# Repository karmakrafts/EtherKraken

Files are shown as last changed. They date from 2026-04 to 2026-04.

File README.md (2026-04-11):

# EtherKraken

An RP3A0 SiP based controller board with 38 programmable IOs, 2MB of flash, SPI, I²C, UART and 100Base-T connectivity
for embedded- and automation-applications.

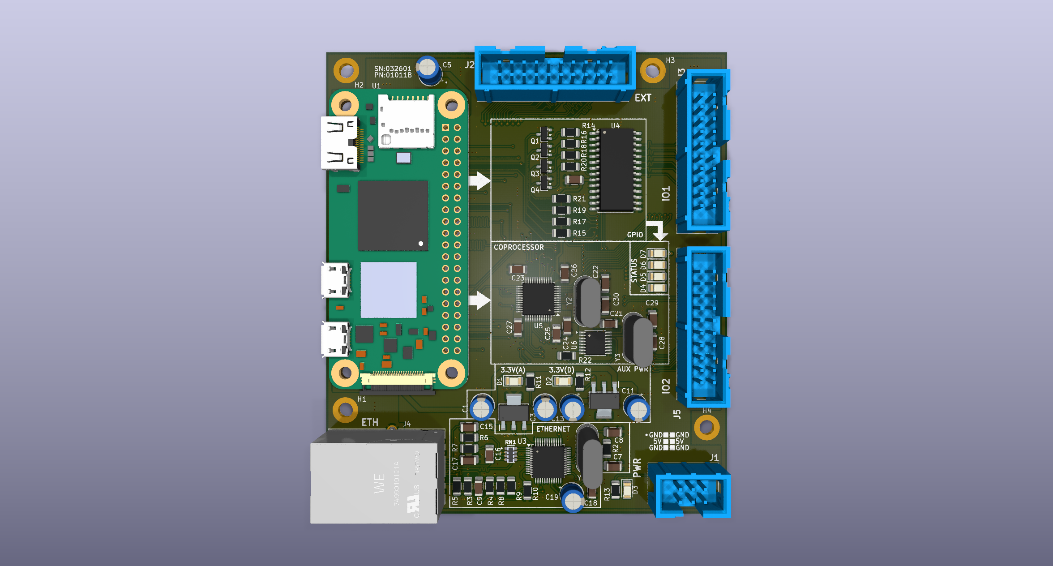
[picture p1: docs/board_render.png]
3D render of the circuit board


### Building libkraken

In order to build the `libkraken` hardware abstraction layer library,  
a computer or VM with a Debian/Ubuntu based Linux distribution is recommended.

The following dependencies are required:

```
build-essential clang-20 llvm-20 make cmake
```

You will also need the Clang RT libraries from an LLVM aarch64 sysroot,  
which you can obtain by downloading a prebuilt LLVM package [from here](https://github.com/llvm/llvm-project/releases)
and  
copying the `aarch-64-unknown-linux-gnu` directory in `LLVM-XX.X.X-Linux-ARM64/lib/clang/XX/lib`  
to `/usr/lib/llvm-XX/lib/clang/XX/lib`.

When you have all dependencies installed, simply invoke `build.sh` in the `libkraken` directory.

The toolchain configuration can be found in `libkraken/cmake/toolchain.cmake` and may be customized as desired.

### Building etherkraken-core

`etherkraken-core` is the high level Kotlin/Native wrapper around the `libkraken` HAL.  
In order to build it, you only need [a JDK](https://www.azul.com/downloads/?package=jdk#zulu) on an Ubuntu/Debian based
Linux distribution.

Simply run the following command in the root of the repository:

```shell
./gradlew build
```

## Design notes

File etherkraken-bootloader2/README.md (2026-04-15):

# EtherKraken bootloader2

bootloader2 (or BL2) is a second stage bootloader for the co-processor  
on the EtherKraken controller board,  
which allows sideloading and flashing firmware via UART to facilitate debugging  
and updates coordinated by the main processor.

### Building

For building EtherKraken bootloader2, a machine or VM with an Ubuntu based distribution  
is recommended. Ensure you have all dependencies installed before proceeding by
running the following command:

```shell
sudo apt install -y build-essential curl wget unzip xz-utils \
	git cmake python3 clang-20 llvm-20 gcc-arm-none-eabi
```

When you have all dependencies installed, simply invoke the image buildscript:

```shell
./build.sh
```

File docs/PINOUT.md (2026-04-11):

# EtherKraken Pinout

The following tables denote the pinouts of all ports and peripherals on
the EtherKraken v1 Rev. B board.  
The Raspberry Pi Zero 2W daughterboard uses the regular BCM2835 GPIO pinout.

### Status LEDs

| Name | Description  | Connects to |
|---|---|---|
| `ST_LED0` | Status LED 0 | MCP23017 GPB4/Pin 5 |
| `ST_LED1` | Status LED 1 | MCP23017 GPB5/Pin 6 |
| `ST_LED2` | Status LED 2 | MCP23017 GPB6/Pin 7 |
| `ST_LED3` | Status LED 3 | MCP23017 GPB7/Pin 8 |

### PWR Port

| Pin | Name | Description | Connects to |
|-----|---|---|---|
| 1 | `GND`  | | GND |
| 3 | `VCC5` | 5V main supply | VCC5 |
| 5 | `GND`  | | GND |
| 2 | `GND`  | | GND |
| 4 | `VCC5` | 5V main supply | VCC5 |
| 6 | `GND`  | | GND |

### EXT Port

| Pin | Name | Description | Connects to |
|-----|---|---|---|
| 1 | `I2C_SCL` | I²C clock | RP3A0 GPIO 3/Pin 5 |
| 3 | `I2C_SDA` | I²C data | RP3A0 GPIO 2/Pin 3 |
| 5 | `GND` | | GND |
| 7 | `GND` | | GND |
| 9 | `SPI1_CE1` | SPI1 chip enable 1 | RP3A0 GPIO 17/Pin 11 |
| 11  | `SPI1_CE2` | SPI1 chip enable 2 | RP3A0 GPIO 16/Pin 36 |
| 13  | `SPI1_MISO`  | SPI1 data from slave | RP3A0 GPIO 19/Pin 35 |
| 15  | `SPI1_MOSI`  | SPI1 data to slave | RP3A0 GPIO 20/Pin 38 |
| 17  | `SPI1_SCLK`  | SPI1 clock | RP3A0 GPIO 21/Pin 40 |
| 19  | `GND` | | GND |
| 2 | `UART_TX` | UART transmit | RP3A0 GPIO 14/Pin 8  |
| 4 | `UART_RX` | UART receive | RP3A0 GPIO 15/Pin 10 |
| 6 | `GND` | | GND |
| 8 | `CO_RST` | Co-processor reset | RP3A0 GPIO 22/Pin 15 |
| 10  | `CO_BOOT` | Co-processor boot mode | RP3A0 GPIO 23/Pin 16 |
| 12  | `CO_SINT` | Co-processor serial interrupt | RP3A0 GPIO 24/Pin 18 |
| 14  | `AUX0` | Auxillary GPIO 0 | RP3A0 GPIO 25/Pin 22 |
| 16  | `AUX1` | Auxillary GPIO 1 | RP3A0 GPIO 26/Pin 37 |
| 18  | `AUX_PWR_EN` | Auxillary power enable (3.3V) | RP3A0 GPIO 27/Pin 13 |
| 20  | `GND` | | GND |

### IO0 Port

| Pin | Name | Description | Connects to |
|-----|---|---|---|
| 1 | `GND` | | GND |
| 3 | `IO_A0` | Primary GPIO 0 | STM32 PA0/Pin 10 |
| 5 | `IO_A1` | Primary GPIO 1 | STM32 PA1/Pin 11 |
| 7 | `IO_A2` | Primary GPIO 2 | STM32 PA2/Pin 12 |
| 9 | `IO_A3` | Primary GPIO 3 | STM32 PA3/Pin 13 |
| 11  | `IO_A4` | Primary GPIO 4 | STM32 PA4/Pin 14 |
| 13  | `IO_A5` | Primary GPIO 5 | STM32 PA5/Pin 15 |
| 15  | `IO_A6` | Primary GPIO 6 | STM32 PA6/Pin 16 |
| 17  | `IO_A7` | Primary GPIO 7 | STM32 PA7/Pin 17 |
| 19  | `GND` | | GND |
| 2 | `GND` | | GND |
| 4 | `IO_B0` | Secondary GPIO 0 | MCP23017 GPA0/Pin 21 |
| 6 | `IO_B1` | Secondary GPIO 1 | MCP23017 GPA0/Pin 22 |
| 8 | `IO_B2` | Secondary GPIO 2 | MCP23017 GPA0/Pin 23 |
| 10  | `IO_B3` | Secondary GPIO 3 | MCP23017 GPA0/Pin 24 |
| 12  | `IO_B4` | Secondary GPIO 4 | MCP23017 GPA0/Pin 25 |
| 14  | `IO_B5` | Secondary GPIO 5 | MCP23017 GPA0/Pin 26 |
| 16  | `IO_A8` | Primary GPIO 8 | STM32 PA8/Pin 29 |
| 18  | `IO_A9` | Primary GPIO 9 | STM32 PB0/Pin 18 |
| 20  | `GND` | | GND |

### IO1 Port

| Pin | Name | Description | Connects to |
|-----|---|---|---|
| 1 | `GND` | | GND |
| 3 | `IO_A10` | Primary GPIO 10 | STM32 PB1/Pin 19 |
| 5 | `IO_A11` | Primary GPIO 11 | STM32 PB2/Pin 20 |
| 7 | `IO_A12` | Primary GPIO 12 | STM32 PB3/Pin 39 |
| 9 | `IO_A13` | Primary GPIO 13 | STM32 PA13/Pin 34 |
| 11  | `IO_A14` | Primary GPIO 14 | STM32 PA14/Pin 37 |
| 13  | `IO_A15` | Primary GPIO 15 | STM32 PA15/Pin 38 |
| 15  | `IO_A16` | Primary GPIO 16 | STM32 PB4/Pin 40 |
| 17  | `IO_A17` | Primary GPIO 17 | STM32 PB5/Pin 41 |
| 19  | `GND` | | GND |
| 2 | `GND` | | GND |
| 4 | `IO_B6`  | Secondary GPIO 6  | MCP23017 GPA6/Pin 27 |
| 6 | `IO_B7`  | Secondary GPIO 7  | MCP23017 GPA7/Pin 28 |
| 8 | `IO_B8`  | Secondary GPIO 8  | MCP23017 GPB0/Pin 1  |
| 10  | `IO_B9`  | Secondary GPIO 9  | MCP23017 GPB1/Pin 2  |
| 12  | `IO_B10` | Secondary GPIO 10 | MCP23017 GPB2/Pin 3  |
| 14  | `IO_B11` | Secondary GPIO 11 | MCP23017 GPB3/Pin 4  |
| 16  | `IO_A18` | Primary GPIO 18 | STM32 PB6/Pin 42 |
| 18  | `IO_A19` | Primary GPIO 19 | STM32 PB7/Pin 43 |
| 20  | `GND` | | GND |

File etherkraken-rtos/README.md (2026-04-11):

# EtherKraken RTOS

EtherKraken RTOS is a modified version of Raspberry Pi OS Lite, incorporating  
PREEMPT_RT kernel patches, default configurations and custom software.

### Building

For building EtherKraken RTOS, a machine or VM with an Ubuntu based distribution  
is recommended. Ensure you have all dependencies installed before proceeding by
running the following command:

```shell
sudo apt install -y build-essential curl wget unzip xz-utils \
    git bc bison flex libncurses5-dev libssl-dev \
    crossbuild-essential-arm64 kmod rsync \
    device-tree-compiler parted
```

When you have all dependencies installed, simply invoke the image buildscript:

```shell
sudo ./build.sh
```

> **Note:** root permission is required to run the buildscript, since it 
> interacts with loopback devices on the build host.

The build was last successfully tested on **PopOS 24.04**.

### Configuration

The default build configuration is specified in `build.sh` directly and may  
be changed as required.  
The default user is `etherkraken` with the default password of `etherkraken`.

#### Boot

The boot configuration may be changed by adjusting `boot/config.txt` and  
`boot/cmdline.txt` accordingly.  
The latter will be appended to the default `cmdline.txt` already included  
in the base image.

#### Network

If a default network configuration should be baked into the built image,  
a `network-config` file needs to be placed in `etherkraken-rtos` root directory  
before invoking `build.sh`.

An example of this can be found in `example/network-config`.

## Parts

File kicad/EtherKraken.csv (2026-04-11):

Reference | Qty | Value | DNP | Exclude from BOM | Exclude from Board | Footprint | Datasheet
C1 | 1 | 2,2µF |  |  |  | Capacitor_THT:CP_Radial_D5.0mm_P2.00mm
C2,C4,C6,C10,C12,C14,C20,C23,C24,C25,C26,C27,C30 | 13 | 100nF |  |  |  | Capacitor_SMD:C_1206_3216Metric
C3,C11 | 2 | 4,7µF |  |  |  | Capacitor_THT:CP_Radial_D5.0mm_P2.00mm
C5,C13 | 2 | 10µF |  |  |  | Capacitor_THT:CP_Radial_D5.0mm_P2.00mm
C7,C8,C21,C22 | 4 | 18pF |  |  |  | Capacitor_SMD:C_1206_3216Metric
C9 | 1 | 22nF |  |  |  | Capacitor_SMD:C_1206_3216Metric
C15,C16 | 2 | 6.8nF |  |  |  | Capacitor_SMD:C_1206_3216Metric
C17,C18 | 2 | 10nF |  |  |  | Capacitor_SMD:C_1206_3216Metric
C19 | 1 | 4.7µF |  |  |  | Capacitor_THT:CP_Radial_D5.0mm_P2.00mm
C28 | 1 | 22pF |  |  |  | Capacitor_SMD:C_1206_3216Metric
C29 | 1 | 33pF |  |  |  | Capacitor_SMD:C_1206_3216Metric
D1,D2,D3,D4,D5,D6,D7 | 7 | LED |  |  |  | LED_SMD:LED_1206_3216Metric
IC1,IC2 | 2 | NCV33375ST3.3T3G |  |  |  | parts:SOT230P700X175-4N | https://www.onsemi.com/pub/Collateral/MC33375-D.PDF
J1 | 1 | Conn_02x03_Odd_Even |  |  |  | parts:09185066324_02x03_P2.54
J2,J3,J5 | 3 | Conn_02x10_Odd_Even |  |  |  | parts:09185206324_02x10_P2.54
J4 | 1 | RJ45_Wuerth_7499010121A |  |  |  | Connector_RJ:RJ45_Wuerth_7499010121A_Horizontal | http://katalog.we-online.de/pbs/datasheet/7499010121A.pdf
Q1,Q2,Q3,Q4 | 4 | MMBT3904 |  |  |  | Package_TO_SOT_SMD:SOT-23 | https://www.onsemi.com/pdf/datasheet/pzt3904-d.pdf
R1,R22 | 2 | 10k |  |  |  | Resistor_SMD:R_1206_3216Metric
R2 | 1 | 1M |  |  |  | Resistor_SMD:R_1206_3216Metric
R3,R4,R6,R7 | 4 | 49,9R |  |  |  | Resistor_SMD:R_1206_3216Metric
R5 | 1 | 10R |  |  |  | Resistor_SMD:R_1206_3216Metric
R8,R9 | 2 | 330R |  |  |  | Resistor_SMD:R_1206_3216Metric
R10 | 1 | 12.4k |  |  |  | Resistor_SMD:R_1206_3216Metric
R11,R12 | 2 | 51R |  |  |  | Resistor_SMD:R_1206_3216Metric
R13 | 1 | 150R |  |  |  | Resistor_SMD:R_1206_3216Metric
R14,R16,R18,R20 | 4 | 1,2k |  |  |  | Resistor_SMD:R_1206_3216Metric
R15,R17,R19,R21 | 4 | 62R |  |  |  | Resistor_SMD:R_1206_3216Metric
RN1 | 1 | 33R |  |  |  | parts:R_Array_Convex_8N_1206
U1 | 1 | RASPBERRY_PI_ZERO_2_W |  |  |  | parts:MODULE_RASPBERRY_PI_ZERO_2_W
U2 | 1 | AT45DB641E-SHN-T |  |  |  | Package_SO:SOIC-8_5.3x5.3mm_P1.27mm
U3 | 1 | W5500 |  |  |  | Package_QFP:LQFP-48_7x7mm_P0.5mm | http://wizwiki.net/wiki/lib/exe/fetch.php/products:w5500:w5500_ds_v109e.pdf
U4 | 1 | MCP23017x-x-SO |  |  |  | Package_SO:SOIC-28W_7.5x17.9mm_P1.27mm | https://ww1.microchip.com/downloads/aemDocuments/documents/APID/ProductDocuments/DataSheets/MCP23017-Data-Sheet-DS20001952.pdf
U5 | 1 | STM32F071CBTx |  |  |  | Package_QFP:LQFP-48_7x7mm_P0.5mm | https://www.st.com/resource/en/datasheet/stm32f071cb.pdf
U6 | 1 | SC16IS740 |  |  |  | Package_SO:TSSOP-16_4.4x5mm_P0.65mm | https://www.nxp.com/docs/en/data-sheet/SC16IS740_750_760.pdf
Y1 | 1 | 25MHz |  |  |  | Crystal:Crystal_HC49-U_Vertical
Y2 | 1 | 8MHz |  |  |  | Crystal:Crystal_HC49-U_Vertical
Y3 | 1 | 1,8432MHz |  |  |  | Crystal:Crystal_HC49-U_Vertical

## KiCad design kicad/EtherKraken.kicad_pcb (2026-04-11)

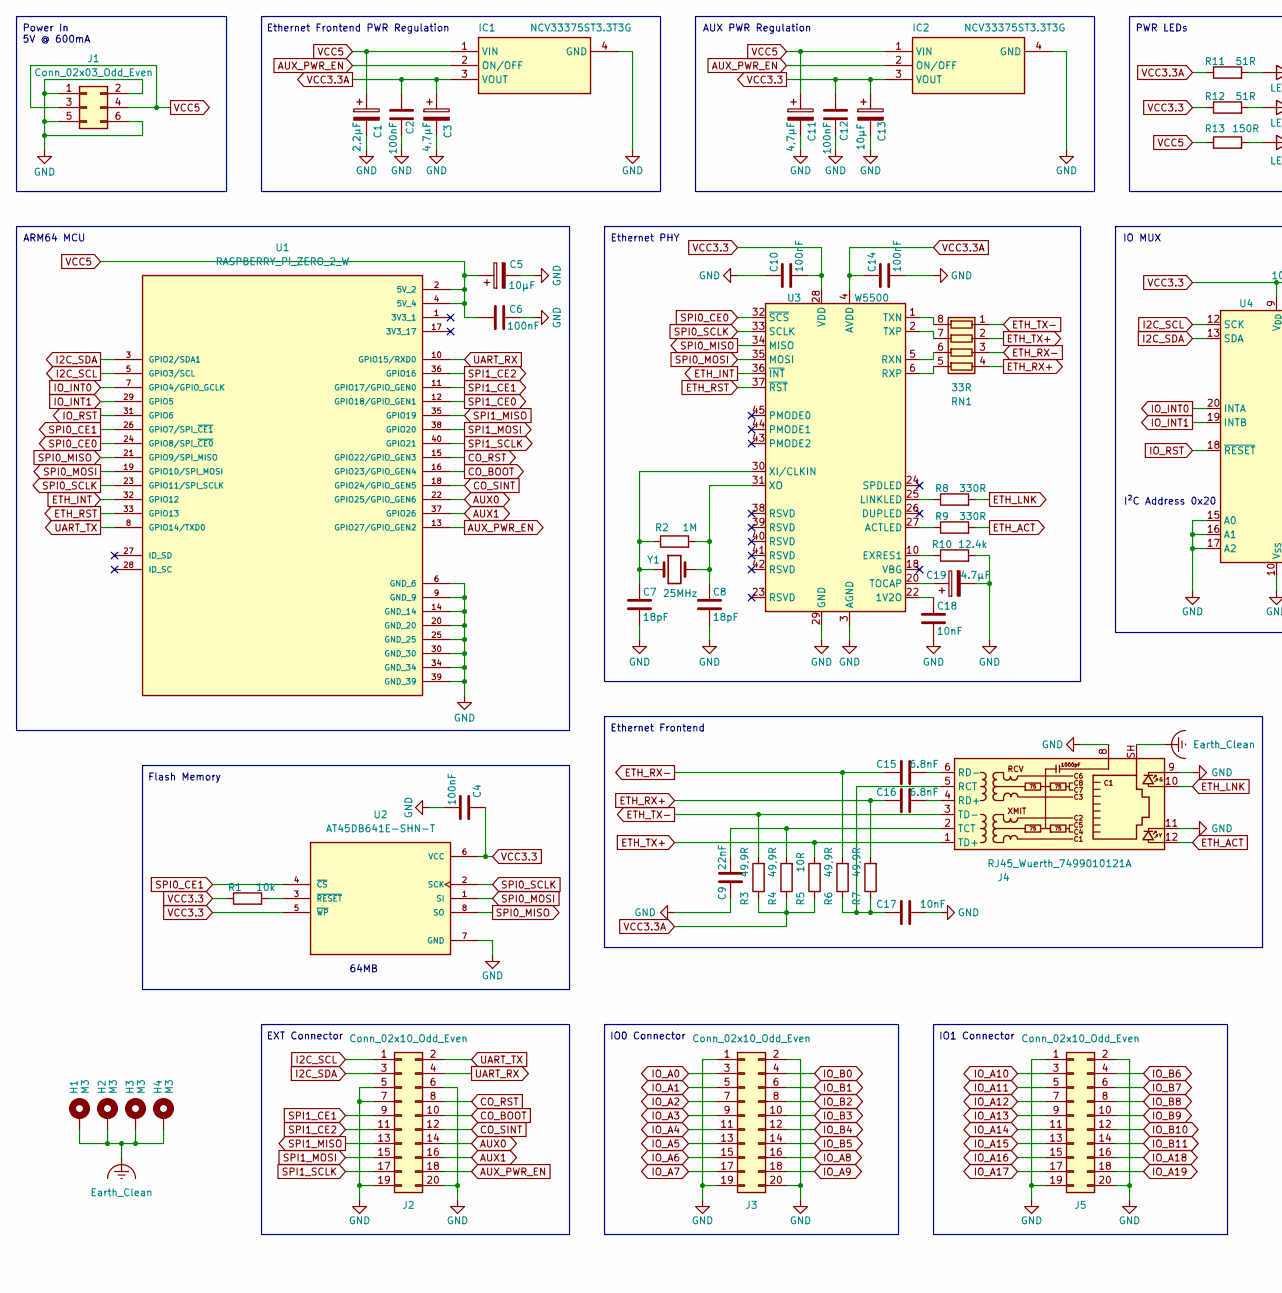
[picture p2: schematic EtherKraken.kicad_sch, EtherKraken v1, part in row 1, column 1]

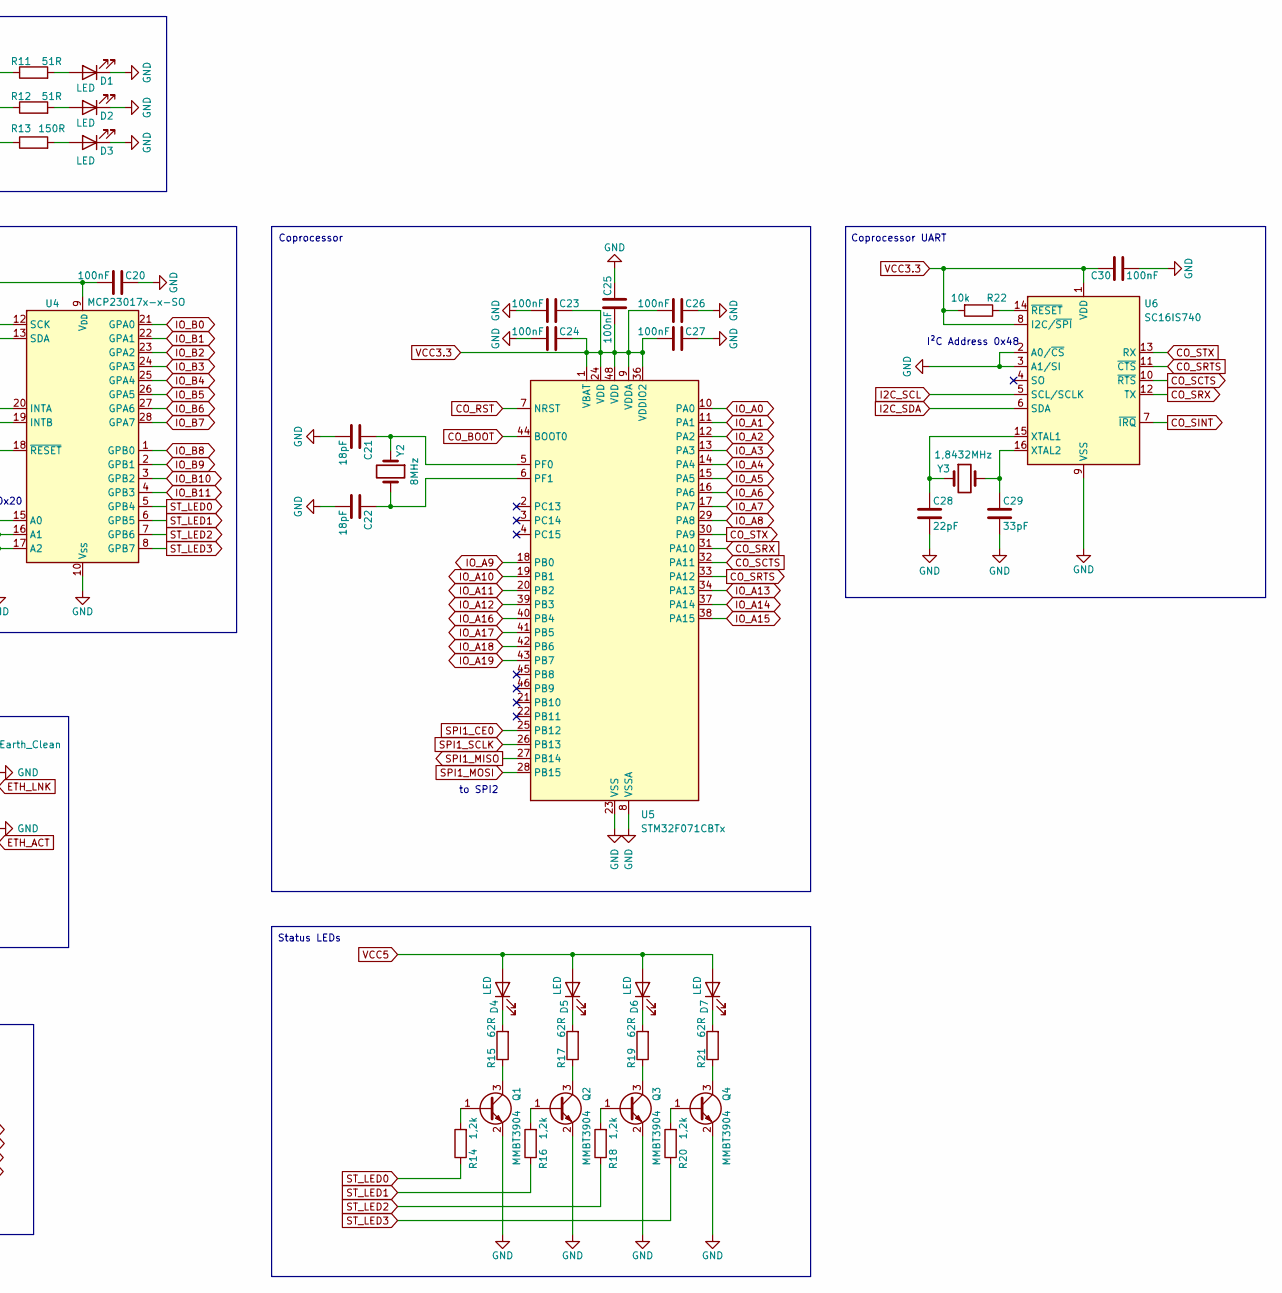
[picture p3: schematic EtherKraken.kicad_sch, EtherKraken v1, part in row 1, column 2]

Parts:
C1: 2,2µF; CP_Radial_D5.0mm_P2.00mm
C2, C4, C6, C10, C12, C14, C20, C23, C24, C25, C26, C27, C30: 100nF; C_1206_3216Metric
C3, C11: 4,7µF; CP_Radial_D5.0mm_P2.00mm
C5, C13: 10µF; CP_Radial_D5.0mm_P2.00mm
C7, C8, C21, C22: 18pF; C_1206_3216Metric
C9: 22nF; C_1206_3216Metric
C15, C16: 6.8nF; C_1206_3216Metric
C17, C18: 10nF; C_1206_3216Metric
C19: 4.7µF; CP_Radial_D5.0mm_P2.00mm
C28: 22pF; C_1206_3216Metric
C29: 33pF; C_1206_3216Metric
D1, D2, D3, D4, D5, D6, D7: LED; LED_1206_3216Metric
H1, H2, H3, H4: M3; MountingHole_3.2mm_M3_DIN965_Pad
IC1, IC2: NCV33375ST3.3T3G; SOT230P700X175-4N; Mouser Part Number 863-NCV33375ST3.3T3G
J1: Conn_02x03_Odd_Even; 09185066324_02x03_P2.54
J2, J3, J5: Conn_02x10_Odd_Even; 09185206324_02x10_P2.54
J4: RJ45_Wuerth_7499010121A; RJ45_Wuerth_7499010121A_Horizontal
Q1, Q2, Q3, Q4: MMBT3904; SOT-23
R1, R22: 10k; R_1206_3216Metric
R2: 1M; R_1206_3216Metric
R3, R4, R6, R7: 49,9R; R_1206_3216Metric
R5: 10R; R_1206_3216Metric
R8, R9: 330R; R_1206_3216Metric
R10: 12.4k; R_1206_3216Metric
R11, R12: 51R; R_1206_3216Metric
R13: 150R; R_1206_3216Metric
R14, R16, R18, R20: 1,2k; R_1206_3216Metric
R15, R17, R19, R21: 62R; R_1206_3216Metric
RN1: 33R; R_Array_Convex_8N_1206
U1: RASPBERRY_PI_ZERO_2_W; MODULE_RASPBERRY_PI_ZERO_2_W; PARTREV April 2024
U2: AT45DB641E-SHN-T; SOIC-8_5.3x5.3mm_P1.27mm
U3: W5500; LQFP-48_7x7mm_P0.5mm
U4: MCP23017x-x-SO; SOIC-28W_7.5x17.9mm_P1.27mm
U5: STM32F071CBTx; LQFP-48_7x7mm_P0.5mm
U6: SC16IS740; TSSOP-16_4.4x5mm_P0.65mm
Y1: 25MHz; Crystal_HC49-U_Vertical
Y2: 8MHz; Crystal_HC49-U_Vertical
Y3: 1,8432MHz; Crystal_HC49-U_Vertical

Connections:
AUX0: J2.14, U1.22 (GPIO25/GPIO_GEN6)
AUX1: J2.16, U1.37 (GPIO26)
AUX_PWR_EN: IC1.2 (ON/OFF), IC2.2 (ON/OFF), J2.18, U1.13 (GPIO27/GPIO_GEN2)
CO_BOOT: J2.10, U1.16 (GPIO23/GPIO_GEN4), U5.44 (BOOT0)
CO_RST: J2.8, U1.15 (GPIO22/GPIO_GEN3), U5.7 (NRST)
CO_SCTS: U5.32 (PA11), U6.10 (~RTS)
CO_SINT: J2.12, U1.18 (GPIO24/GPIO_GEN5), U6.7 (~IRQ)
CO_SRTS: U5.33 (PA12), U6.11 (~CTS)
CO_SRX: U5.31 (PA10), U6.12 (TX)
CO_STX: U5.30 (PA9), U6.13 (RX)
ETH_ACT: J4.12, R9.2
ETH_INT: U1.32 (GPIO12), U3.36 (~INT)
ETH_LNK: J4.10, R8.2
ETH_RST: U1.33 (GPIO13), U3.37 (~RST)
ETH_RX+: C16.1, R7.2, RN1.4 (R4.1)
ETH_RX-: C15.1, R6.2, RN1.3 (R3.1)
ETH_TX+: J4.1 (TD+), R5.2, RN1.2 (R2.1)
ETH_TX-: J4.3 (TD-), R3.2, RN1.1 (R1.1)
Earth_Clean: H1.1 (1_1), H2.1 (1_1), H3.1 (1_1), H4.1 (1_1), J4.SH
GND: C1.2, C2.1, C3.2, C4.2, C5.2, C6.2, C7.2, C8.2, C9.1, C10.1, C11.2, C12.1, C13.2, C14.2, C17.2, C18.2, C19.2, C20.1, C21.2, C22.2, C23.2, C24.2, C25.1, C26.1, C27.1, C28.2, C29.2, C30.2, D1.1 (K), D2.1 (K), D3.1 (K), IC1.4 (GND), IC2.4 (GND), J1.1, J1.2, J1.5, J1.6, J2.5, J2.6, J2.7, J2.19, J2.20, J3.1, J3.2, J3.19, J3.20, J4.8, J4.9, J4.11, J5.1, J5.2, J5.19, J5.20, Q1.2 (E), Q2.2 (E), Q3.2 (E), Q4.2 (E), R10.2, U1.6 (GND_6), U1.9 (GND_9), U1.14 (GND_14), U1.20 (GND_20), U1.25 (GND_25), U1.30 (GND_30), U1.34 (GND_34), U1.39 (GND_39), U2.7 (GND), U3.3 (AGND), U3.9 (AGND), U3.14 (AGND), U3.16 (AGND), U3.19 (AGND), U3.29 (GND), U3.48 (AGND), U4.10 (V_{SS}), U4.15 (A0), U4.16 (A1), U4.17 (A2), U5.8 (VSSA), U5.23 (VSS), U5.35 (VSS), U5.47 (VSS), U6.2 (A0/~CS), U6.3 (A1/SI), U6.9 (VSS)
I2C_SCL: J2.1, U1.5 (GPIO3/SCL), U4.12 (SCK), U6.5 (SCL/SCLK)
I2C_SDA: J2.3, U1.3 (GPIO2/SDA1), U4.13 (SDA), U6.6 (SDA)
IO_A0: J3.3, U5.10 (PA0)
IO_A1: J3.5, U5.11 (PA1)
IO_A2: J3.7, U5.12 (PA2)
IO_A3: J3.9, U5.13 (PA3)
IO_A4: J3.11, U5.14 (PA4)
IO_A5: J3.13, U5.15 (PA5)
IO_A6: J3.15, U5.16 (PA6)
IO_A7: J3.17, U5.17 (PA7)
IO_A8: J3.16, U5.29 (PA8)
IO_A9: J3.18, U5.18 (PB0)
IO_A10: J5.3, U5.19 (PB1)
IO_A11: J5.5, U5.20 (PB2)
IO_A12: J5.7, U5.39 (PB3)
IO_A13: J5.9, U5.34 (PA13)
IO_A14: J5.11, U5.37 (PA14)
IO_A15: J5.13, U5.38 (PA15)
IO_A16: J5.15, U5.40 (PB4)
IO_A17: J5.17, U5.41 (PB5)
IO_A18: J5.16, U5.42 (PB6)
IO_A19: J5.18, U5.43 (PB7)
IO_B0: J3.4, U4.21 (GPA0)
IO_B1: J3.6, U4.22 (GPA1)
IO_B2: J3.8, U4.23 (GPA2)
IO_B3: J3.10, U4.24 (GPA3)
IO_B4: J3.12, U4.25 (GPA4)
IO_B5: J3.14, U4.26 (GPA5)
IO_B6: J5.4, U4.27 (GPA6)
IO_B7: J5.6, U4.28 (GPA7)
IO_B8: J5.8, U4.1 (GPB0)
IO_B9: J5.10, U4.2 (GPB1)
IO_B10: J5.12, U4.3 (GPB2)
IO_B11: J5.14, U4.4 (GPB3)
IO_INT0: U1.7 (GPIO4/GPIO_GCLK), U4.20 (INTA)
IO_INT1: U1.29 (GPIO5), U4.19 (INTB)
IO_RST: U1.31 (GPIO6), U4.18 (~RESET)
unnamed: D1.2 (A), R11.2
unnamed: D2.2 (A), R12.2
unnamed: D3.2 (A), R13.2
unnamed: D4.1 (K), R15.2
unnamed: D5.1 (K), R17.2
unnamed: D6.1 (K), R19.2
unnamed: D7.1 (K), R21.2
unnamed: C17.1, J4.5 (RCT), R6.1, R7.1
unnamed: C16.2, J4.4 (RD+)
unnamed: C15.2, J4.6 (RD-)
unnamed: C9.2, J4.2 (TCT), R4.2
unnamed: Q1.1 (B), R14.2
unnamed: Q1.3 (C), R15.1
unnamed: Q2.1 (B), R16.2
unnamed: Q2.3 (C), R17.1
unnamed: Q3.1 (B), R18.2
unnamed: Q3.3 (C), R19.1
unnamed: Q4.1 (B), R20.2
unnamed: Q4.3 (C), R21.1
unnamed: RN1.8 (R1.2), U3.1 (TXN)
unnamed: RN1.7 (R2.2), U3.2 (TXP)
unnamed: RN1.6 (R3.2), U3.5 (RXN)
unnamed: RN1.5 (R4.2), U3.6 (RXP)
unnamed: R1.2, U2.3 (~RESET)
unnamed: C18.1, U3.22 (1V2O)
unnamed: R9.1, U3.27 (ACTLED)
unnamed: R10.1, U3.10 (EXRES1)
unnamed: R8.1, U3.25 (LINKLED)
unnamed: C19.1, U3.20 (TOCAP)
unnamed: C7.1, R2.1, U3.30 (XI/CLKIN), Y1.1
unnamed: C8.1, R2.2, U3.31 (XO), Y1.2
unnamed: C21.1, U5.5 (PF0), Y2.1
unnamed: C22.1, U5.6 (PF1), Y2.2
unnamed: C28.1, U6.15 (XTAL1), Y3.1
unnamed: C29.1, U6.16 (XTAL2), Y3.2
unnamed: R22.1, U6.14 (~RESET)
SPI0_CE0: U1.24 (GPIO8/SPI_~CE0), U3.32 (~SCS)
SPI0_CE1: U1.26 (GPIO7/SPI_~CE1), U2.4 (~CS)
SPI0_MISO: U1.21 (GPIO9/SPI_MISO), U2.8 (SO), U3.34 (MISO)
SPI0_MOSI: U1.19 (GPIO10/SPI_MOSI), U2.1 (SI), U3.35 (MOSI)
SPI0_SCLK: U1.23 (GPIO11/SPI_SCLK), U2.2 (SCK), U3.33 (SCLK)
SPI1_CE0: U1.12 (GPIO18/GPIO_GEN1), U5.25 (PB12)
SPI1_CE1: J2.9, U1.11 (GPIO17/GPIO_GEN0)
SPI1_CE2: J2.11, U1.36 (GPIO16)
SPI1_MISO: J2.13, U1.35 (GPIO19), U5.27 (PB14)
SPI1_MOSI: J2.15, U1.38 (GPIO20), U5.28 (PB15)
SPI1_SCLK: J2.17, U1.40 (GPIO21), U5.26 (PB13)
ST_LED0: R14.1, U4.5 (GPB4)
ST_LED1: R16.1, U4.6 (GPB5)
ST_LED2: R18.1, U4.7 (GPB6)
ST_LED3: R20.1, U4.8 (GPB7)
UART_RX: J2.4, U1.10 (GPIO15/RXD0)
UART_TX: J2.2, U1.8 (GPIO14/TXD0)
VCC3.3: C4.1, C10.2, C12.2, C13.1, C20.2, C23.1, C24.1, C25.2, C26.2, C27.2, C30.1, IC2.3 (VOUT), R1.1, R12.1, R22.2, U2.5 (~WP), U2.6 (VCC), U3.28 (VDD), U4.9 (V_{DD}), U5.1 (VBAT), U5.9 (VDDA), U5.24 (VDD), U5.36 (VDDIO2), U5.48 (VDD), U6.1 (VDD), U6.8 (I2C/~SPI)
VCC3.3A: C2.2, C3.1, C14.1, IC1.3 (VOUT), R3.1, R4.1, R5.1, R11.1, U3.4 (AVDD), U3.8 (AVDD), U3.11 (AVDD), U3.15 (AVDD), U3.17 (AVDD), U3.21 (AVDD)
VCC5: C1.1, C5.1, C6.1, C11.1, D4.2 (A), D5.2 (A), D6.2 (A), D7.2 (A), IC1.1 (VIN), IC2.1 (VIN), J1.3, J1.4, R13.1, U1.2 (5V_2), U1.4 (5V_4)

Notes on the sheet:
Ethernet Frontend PWR Regulation
PWR LEDs
Ethernet PHY
Coprocessor
AUX PWR Regulation
IO MUX
IO1 Connector
ARM64 MCU
64MB
IO0 Connector
I²C Address 0x20
Coprocessor UART
I²C Address 0x48
Ethernet Frontend
Power In 5V @ 600mA
Flash Memory
Status LEDs
to SPI2
EXT Connector

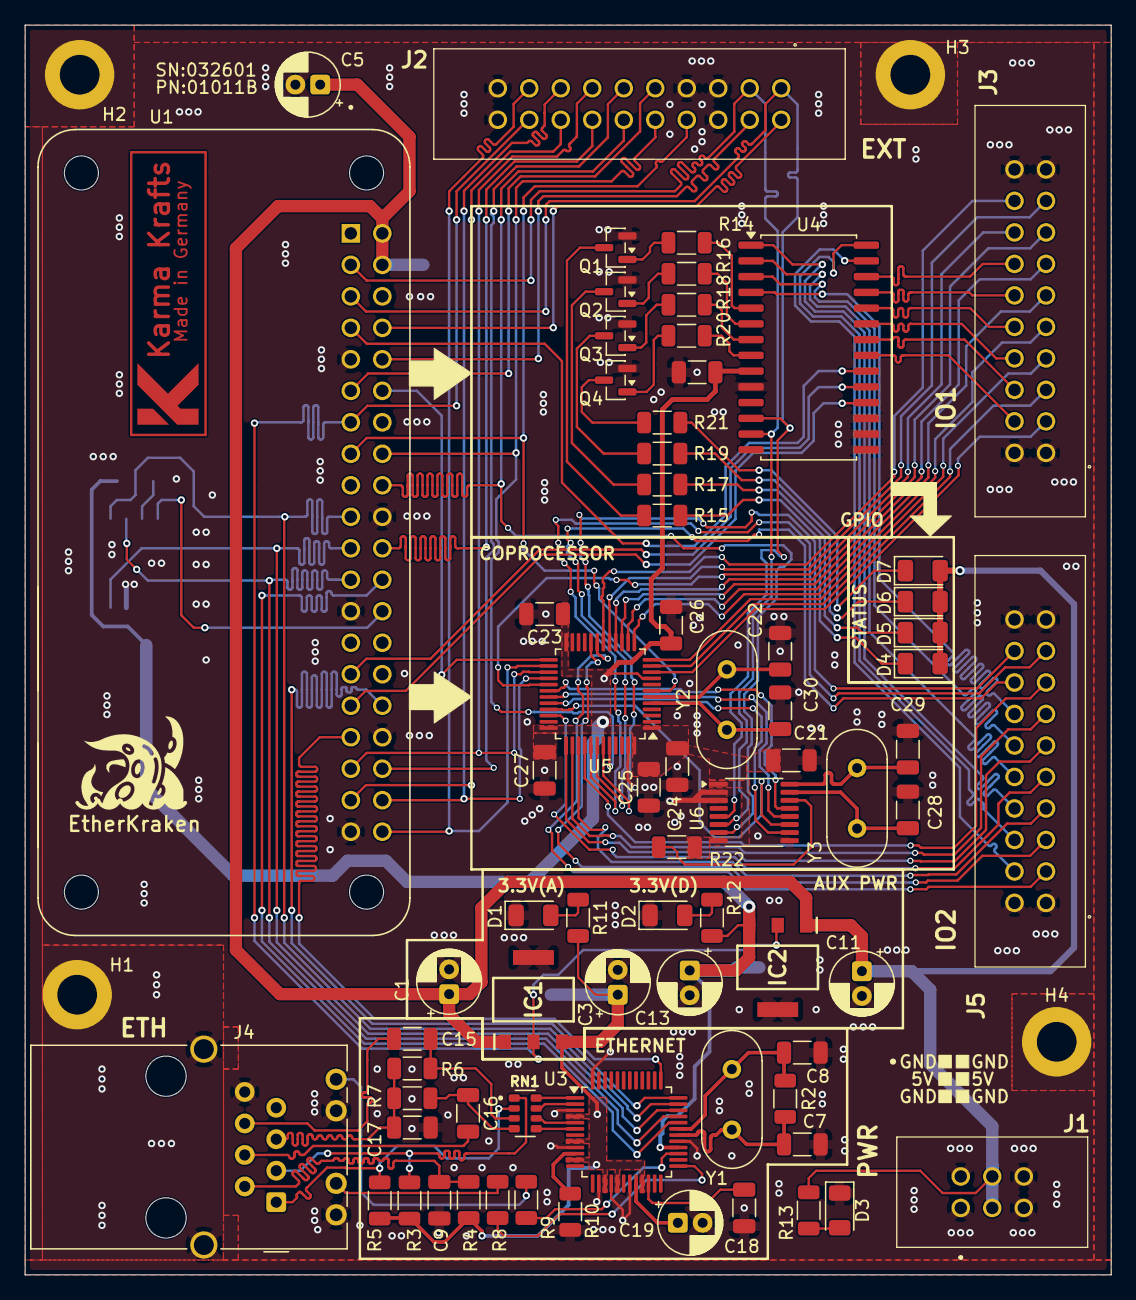
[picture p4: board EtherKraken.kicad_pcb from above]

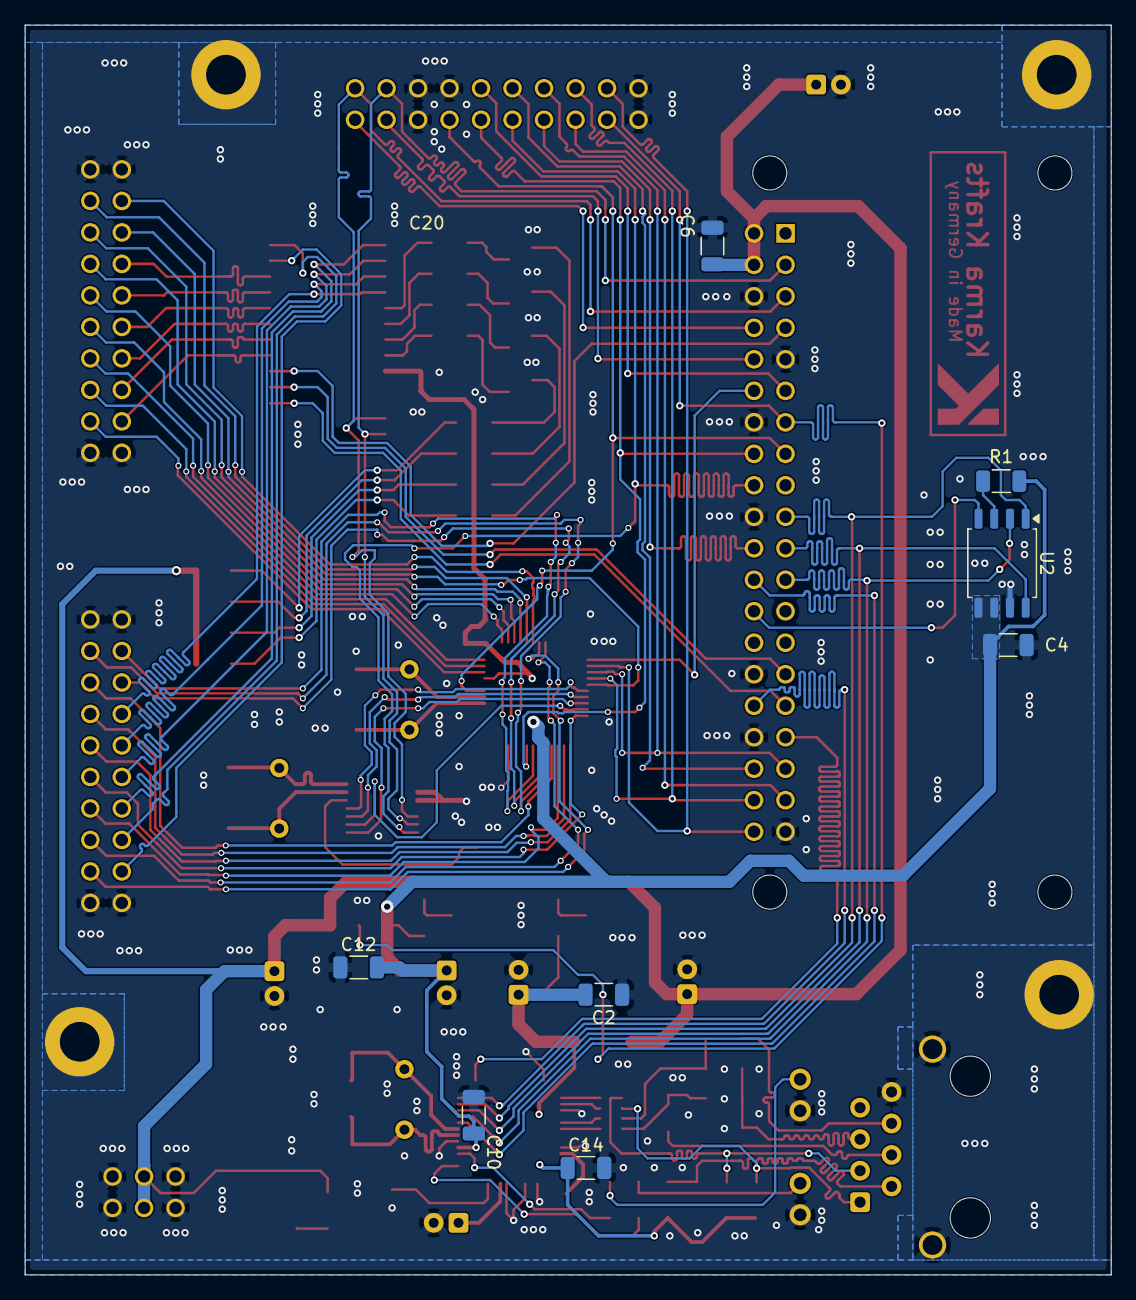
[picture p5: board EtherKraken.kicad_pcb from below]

Board: 2 copper layers, 87.6 x 100.8 mm, 84 parts (8 on the bottom side), 113 nets.

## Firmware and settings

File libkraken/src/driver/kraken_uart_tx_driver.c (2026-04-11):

// Copyright 2026 Karma Krafts
//
// Licensed under the Apache License, Version 2.0 (the "License");
// you may not use this file except in compliance with the License.
// You may obtain a copy of the License at
//
// http://www.apache.org/licenses/LICENSE-2.0
//
// Unless required by applicable law or agreed to in writing, software
// distributed under the License is distributed on an "AS IS" BASIS,
// WITHOUT WARRANTIES OR CONDITIONS OF ANY KIND, either express or implied.
// See the License for the specific language governing permissions and
// limitations under the License.

#include "driver/kraken_driver.h"
#include "kraken_driver_impl.h"
#include "kraken_error_impl.h"
#include "kraken_uart_tx_driver_impl.h"
#include "port/kraken_port_impl.h"

// Standard UART at 0-3.3V logic levels.
// See https://en.wikipedia.org/wiki/Universal_asynchronous_receiver-transmitter.
//
//   3.3V (Logic 1) ┠────┐   ┌───┐       ┌───────────┐   ┌────────────────┨
//                  ┃    │   │   │       │           │   │                ┃
//     0V (Logic 0) ┃    └───┘   └───────┘           └───┘                ┃
//                  ┃ IDL STA DA0 DA1 DA2 DA3 DA4 DA5 DA6 DA7 PAR STP IDL ┃
//
// The idle state of the transmission wire is a logic high at 3.3V.
// The data bits are configurable from 5-8 and parity bit is optional.

static uint64_t kraken_uart_tx_driver_tick(kraken_port_handle_t, void* user_data) {
    if(!user_data) {
        return KRAKEN_DRIVER_IO_MASK_NONE;
    }
    kraken_uart_tx_state_t* state = user_data;

    uint8_t current_byte = atomic_load(&state->byte);
    int8_t current_bit = atomic_load(&state->bit);
    if(current_bit == KRAKEN_UART_TX_STOP_BIT || current_bit == state->last_stop_bit) {
        bool is_empty = false;
        if(kraken_byte_queue_is_empty(state->buffer, &is_empty) != KRAKEN_OK || is_empty) {
            return KRAKEN_DRIVER_IO_MASK_NONE;// No data, no IO gets updated
        }
        if(kraken_byte_queue_dequeue(state->buffer, &current_byte) != KRAKEN_OK) {
            return KRAKEN_DRIVER_IO_MASK_NONE;// Data dequeue failed, no IO gets updated
        }
        atomic_store(&state->byte, current_byte);
        current_bit = state->start_bit;
        atomic_store(&state->bit, current_bit);// Reset to start bit
    }

    if(current_bit == 0) {// Start bit, always logic low
        atomic_store(&state->io->state, KRAKEN_FALSE);
    }
    else if(current_bit >= state->first_data_bit && current_bit <= state->last_data_bit) {// Data bits
        const int32_t bit_index = current_bit - state->first_data_bit;
        const kraken_bool_t bit_value = (kraken_bool_t) (current_byte >> bit_index & 0b1);
        atomic_store(&state->io->state, bit_value);
    }
    else if(state->parity_bit != KRAKEN_UART_TX_NO_PARITY && current_bit == state->parity_bit) {
        const int32_t count = __builtin_popcount(state->byte);
        kraken_bool_t bit_value = KRAKEN_FALSE;
        switch(state->config->parity) {
            case KRAKEN_UART_PARITY_ODD: {
                bit_value = (kraken_bool_t) ((count & 0b1) == 0b1);
                break;
            }
            case KRAKEN_UART_PARITY_EVEN: {
                bit_value = (kraken_bool_t) ((count & 0b1) == 0b0);
                break;
            }
            case KRAKEN_UART_PARITY_MARK: {
                bit_value = KRAKEN_TRUE;
                break;
            }
            default: break;
        }
        atomic_store(&state->io->state, bit_value);
    }
    else if(current_bit >= state->first_stop_bit && current_bit <= state->last_stop_bit) {
        atomic_store(&state->io->state, KRAKEN_TRUE);// Stop bits, always logic high
    }

    atomic_store(&state->bit, current_bit + 1);
    return state->io_mask;
}

KRAKEN_EXPORT kraken_error_t kraken_uart_tx_driver_create(const kraken_uart_config_t* config, kraken_port_handle_t port,
                                                          kraken_driver_handle_t* handle) {
    KRAKEN_CHECK_PTR(handle, KRAKEN_ERR_INVALID_ARG, "Invalid driver handle pointer");

    kraken_uart_tx_state_t* state = kraken_calloc(sizeof(kraken_uart_tx_state_t));
    KRAKEN_CHECK_PTR(state, KRAKEN_ERR_INVALID_OP, "Could not allocate UART TX driver state");
    state->config = kraken_heapcopy_of(config);
    const uint32_t pin = config->pin;
    state->io_mask = KRAKEN_DRIVER_IO_MASK(pin);
    atomic_store(&state->bit, KRAKEN_UART_TX_STOP_BIT);

    // Start bit + parity bit + data bits + stop bits
    state->frame_size = (int8_t) (1 + config->data_bits + config->stop_bits);
    if(config->parity != KRAKEN_UART_PARITY_NONE) {
        state->frame_size++;// Additional parity bit if parity is enabled
    }
    const bool has_parity = config->parity != KRAKEN_UART_PARITY_NONE;
    state->start_bit = 0;// Start bit is always index 0
    state->first_data_bit = 1;
    state->last_data_bit = (int8_t) (config->data_bits + 1);
    state->parity_bit = has_parity ? (int8_t) (state->last_data_bit + 1) : -1;
    state->first_stop_bit = (int8_t) (has_parity ? state->parity_bit + 1 : state->last_data_bit + 1);
    state->last_stop_bit = (int8_t) (state->first_stop_bit + config->stop_bits);

    // Find the matching IO
    for(size_t index = 0; index < port->num_ios; index++) {
        kraken_io_t* io = port->ios[index];
        if(io->pin_config.device_pin != pin) {
            continue;
        }
        state->io = io;
    }
    KRAKEN_CHECK_PTR(state->io, KRAKEN_ERR_INVALID_OP, "Could not find matching IO for UART TX driver");

    atomic_store(&state->io->pud_mode, KRAKEN_IO_PUD_MODE_UP);
    KRAKEN_CHECK_CALL_ERR(kraken_port_reinit(port), "Could not initialize UART TX driver port state");

    atomic_store(&state->io->state, KRAKEN_TRUE);// Idle state is high (stop bit)
    KRAKEN_CHECK_CALL_ERR(kraken_port_update_masked(port, state->io_mask),
                          "Could not initialize UART TX driver port state");

    usleep(1000);// Wait a small moment to reach a stable state

    KRAKEN_CHECK_CALL_ERR(kraken_byte_queue_create(config->buffer_size, &state->buffer),
                          "Could not initialize serial TX queue");

    kraken_driver_handle_t driver = nullptr;
    KRAKEN_CHECK_CALL_ERR(kraken_driver_create(port, &kraken_uart_tx_driver_tick, state, &driver),
                          "Could not create UART TX driver instance");
    *handle = driver;

    return KRAKEN_OK;
}

KRAKEN_EXPORT kraken_error_t kraken_uart_tx_driver_get_config(kraken_driver_c_handle_t handle,
                                                              kraken_uart_config_t** config) {
    KRAKEN_CHECK_PTR(handle, KRAKEN_ERR_INVALID_ARG, "Invalid driver handle");
    KRAKEN_CHECK_PTR(config, KRAKEN_ERR_INVALID_ARG, "Invalid driver config address pointer");
    const kraken_uart_tx_state_t* state = handle->user_data;
    *config = state->config;
    return KRAKEN_OK;
}
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

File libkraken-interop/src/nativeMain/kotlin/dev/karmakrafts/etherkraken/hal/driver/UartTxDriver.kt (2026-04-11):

/*
 * Copyright 2026 Karma Krafts
 *
 * Licensed under the Apache License, Version 2.0 (the "License");
 * you may not use this file except in compliance with the License.
 * You may obtain a copy of the License at
 *
 * http://www.apache.org/licenses/LICENSE-2.0
 *
 * Unless required by applicable law or agreed to in writing, software
 * distributed under the License is distributed on an "AS IS" BASIS,
 * WITHOUT WARRANTIES OR CONDITIONS OF ANY KIND, either express or implied.
 * See the License for the specific language governing permissions and
 * limitations under the License.
 */

@file:OptIn(ExperimentalForeignApi::class)

package dev.karmakrafts.etherkraken.hal.driver

import dev.karmakrafts.etherkraken.hal.Port
import dev.karmakrafts.etherkraken.hal.check
import kotlinx.cinterop.ExperimentalForeignApi
import kotlinx.cinterop.alloc
import kotlinx.cinterop.cValue
import kotlinx.cinterop.cValuesOf
import kotlinx.cinterop.convert
import kotlinx.cinterop.memScoped
import kotlinx.cinterop.ptr
import kotlinx.cinterop.value
import libkraken.kraken_driver_handle_t
import libkraken.kraken_driver_handle_tVar
import libkraken.kraken_uart_parity_t
import libkraken.kraken_uart_tx_driver_create
import libkraken.kraken_uart_tx_driver_destroy
import libkraken.kraken_uart_tx_driver_wait
import libkraken.kraken_uart_tx_driver_write

class UartTxDriver(override val handle: kraken_driver_handle_t) : Driver, AutoCloseable {
    constructor( // @formatter:off
        port: Port,
        pin: UInt,
        dataBits: Int = 8,
        stopBits: Int = 1,
        parity: kraken_uart_parity_t = kraken_uart_parity_t.KRAKEN_UART_PARITY_NONE,
        bufferSize: Int = 4096
    ) : this(memScoped { // @formatter:on
        val handle = alloc<kraken_driver_handle_tVar>()
        kraken_uart_tx_driver_create(cValue {
            buffer_size = bufferSize.toUInt()
            this.pin = pin
            data_bits = dataBits.toByte()
            stop_bits = stopBits.toByte()
            this.parity = parity
        }, port.handle, handle.ptr).check()
        checkNotNull(handle.value) {
            "Could not create serial TX driver"
        }
    })

    fun wait() {
        kraken_uart_tx_driver_wait(handle).check()
    }

    fun write(value: Byte) {
        kraken_uart_tx_driver_write(handle, cValuesOf(value), Byte.SIZE_BYTES.convert()).check()
    }

    fun write(value: Short) {
        kraken_uart_tx_driver_write(handle, cValuesOf(value), Short.SIZE_BYTES.convert()).check()
    }

    fun write(value: Int) {
        kraken_uart_tx_driver_write(handle, cValuesOf(value), Int.SIZE_BYTES.convert()).check()
    }

    fun write(value: Long) {
        kraken_uart_tx_driver_write(handle, cValuesOf(value), Long.SIZE_BYTES.convert()).check()
    }

    fun write(value: UByte) {
        kraken_uart_tx_driver_write(handle, cValuesOf(value), UByte.SIZE_BYTES.convert()).check()
    }

    fun write(value: UShort) {
        kraken_uart_tx_driver_write(handle, cValuesOf(value), UShort.SIZE_BYTES.convert()).check()
    }

    fun write(value: UInt) {
        kraken_uart_tx_driver_write(handle, cValuesOf(value), UInt.SIZE_BYTES.convert()).check()
    }

    fun write(value: ULong) {
        kraken_uart_tx_driver_write(handle, cValuesOf(value), ULong.SIZE_BYTES.convert()).check()
    }

    fun write(value: String) {
        value.encodeToByteArray().forEach(::write)
    }

    override fun close() {
        kraken_uart_tx_driver_destroy(handle).check()
    }
}

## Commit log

2026-03-24 Add KiCad project for v1 Rev. B
2026-03-24 Add uncompressed project files
    [EtherKraken.csv, EtherKraken.kicad_pcb, EtherKraken.kicad_sch]
2026-03-24 Update kicad gitignore
2026-03-25 Implement basic board initialization and flash interface in HAL
    [EtherKraken.kicad_pcb, EtherKraken.kicad_sch]
2026-03-27 Implement separate port types for I2C and SPI MUXes
2026-03-27 Re-implement I2C mux creation
2026-03-27 Implement kraken_board_get_port_for_io, start implementing SPI MUX creation
2026-03-27 Add a proper README
    [EtherKraken.kicad_pcb]
2026-03-28 Implement MCP23017 I2C initialization routine
2026-03-29 Implement basic MCP23017 port state handlers for I2C and SPI
2026-03-30 Add documentation to BCM2835 device header
2026-03-30 Add documentation to MCP23017 device header
2026-03-31 Implement IO driver dispatcher & clocks
2026-03-31 Change driver selftest to 10kHz clock
2026-03-31 Use max priority for IODispatcher, prevent speculative execution inside IO loops of BCM driver
2026-04-01 Implement dispatcher, clocks and drivers in HAL
2026-04-01 Add documentation to new clock/driver API
2026-04-01 Implement update masks to driver callbacks to allow sub-updates in ports
2026-04-01 Implement wrappers for Clock, Dispatcher and Driver. Add update mask support to BCM2835 device state machine.
2026-04-01 Clearly split error validation in HAL into _CALL macros
    [kraken_board.c, kraken_config.c, kraken_gpio_port.c]
2026-04-06 Migrate HAL to CMake presets, add HAL host tests
    [EtherKraken.kicad_pcb]
2026-04-07 Use atomic_queue library for RX/TX driver buffers
2026-04-07 Start implementing UART TX driver
2026-04-08 Add custom RTOS image build script for PREEMPT_RT kernel
    [config.txt]
2026-04-11 Update KiCad files for Revision B
    [EtherKraken.kicad_pcb, EtherKraken.kicad_sch]
2026-04-11 Add PINOUT.md to docs, update board render
    [EtherKraken.kicad_pcb]
2026-04-11 Update BOM
    [EtherKraken.csv]
2026-04-14 Use find_program for arm-none-eabi-gcc in opencm3.cmake
2026-04-15 Start implementing DMA based UART for bootloader2
